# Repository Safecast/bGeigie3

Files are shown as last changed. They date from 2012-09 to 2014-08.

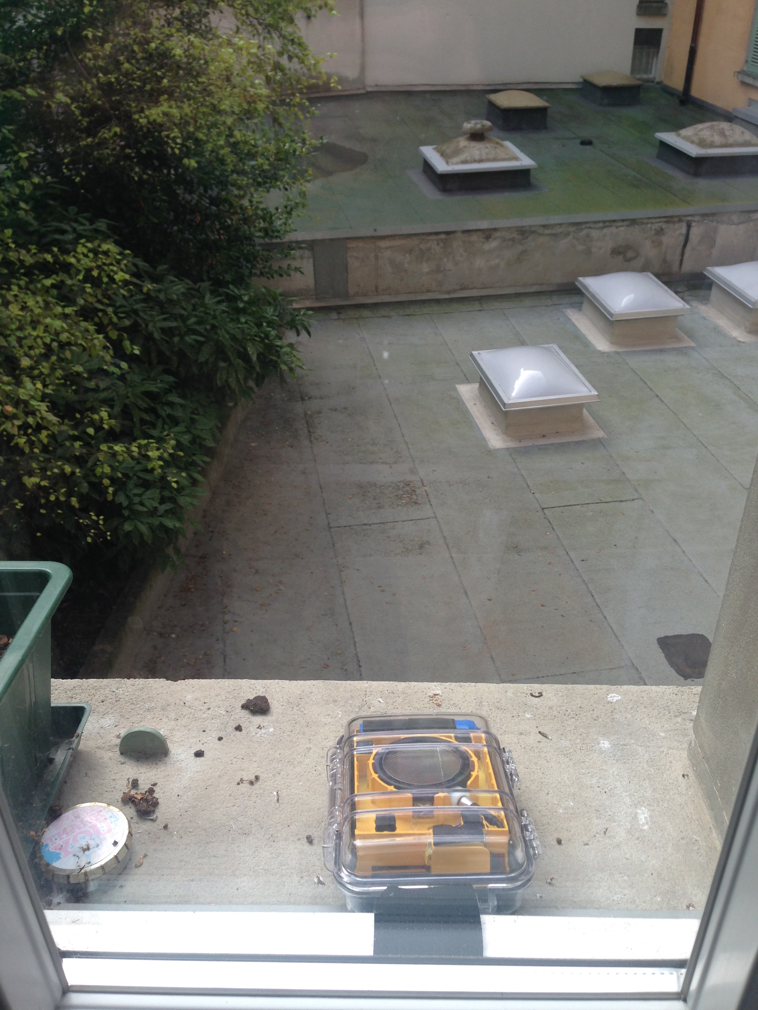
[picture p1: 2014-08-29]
bGeigie3_endurance_august_2014/bGeigie3_placement3.jpg

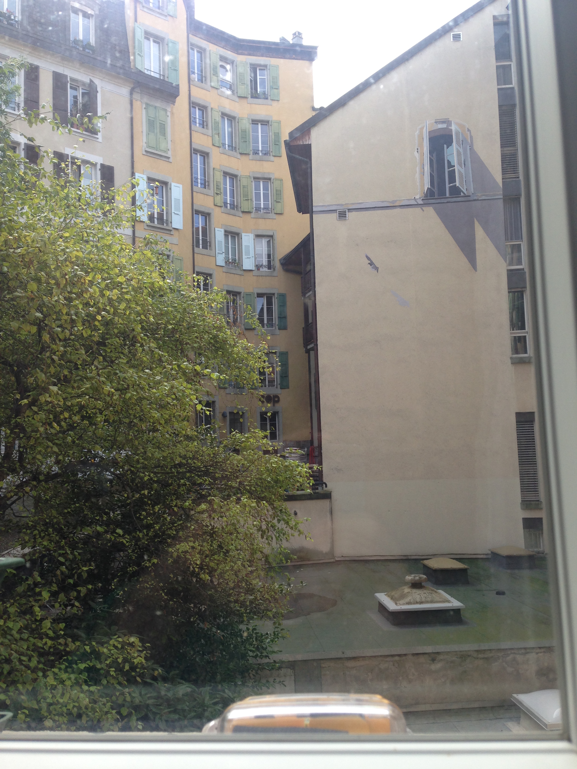
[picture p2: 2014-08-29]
bGeigie3_endurance_august_2014/bGeigie3_placement2.jpg

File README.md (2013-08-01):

## bGeigie3

These are the Eagle CAD files for the bGeigie v3.0 (codename NX) board.

This project is a part of the Safecast radiation monitoring project.
Find out more on [the Safecast website](http://www.safecast.org)

_Note_: although the github repo is named `bGeigie2`, the content is really the **bGeigie3**.

## License

2011-2013 (c) Robin Scheibler
Creative Commons Attribution-ShareAlike 3.0 Unported (CC BY-SA 3.0)
For more details see (http://creativecommons.org/licenses/by-sa/3.0/)

## Produce a bGeigie3

### Gerber

The gerber files can be downloaded [here](https://dl.dropboxusercontent.com/u/78009186/files/bGeigie_v3.4_gerber.zip)

### BOM

The full BOM can be found [here](https://docs.google.com/spreadsheet/ccc?key=0AvXZ3hGhBSusdEQ3NjlfN2hRUnljeTNhNEF5WDNzVWc&usp=sharing).

### Software

* [Firmware](https://github.com/Safecast/SafecastBGeigie)
* [Modded arduino IDE](https://github.com/fakufaku/Arduino) [bin](https://github.com/downloads/fakufaku/Arduino/arduino-Safecast-20121019-macosx.zip)
* [Automated programming tools](https://github.com/Safecast/SCbG3-hexes)

## Tech notes

### Power supply

The system is powered by a LiPo battery providing 4.2V at full charge and dies around 3.5V.

### Battery sensing

The Atmega1284p has two internal analog references: 1.1 or 2.56.

We need to sense the battery voltage between 4.2 and 3.5V.

Let's use a voltage divider with R1 = 100K and R2 = 120K.

Then `Vs = R2/(R1+R2) = 0.54*Vin`, giving a range of 2.3V to 1.89V roughly. We
decide to use the 2.5 reference. This gives use roughly 170 levels of
resolution.

### 50 Ohm trace for the Radio and GPS antennas

* Wiki entry on [microstrips](http://en.wikipedia.org/wiki/Microstrip)
* Microstrip impedance [calculator](http://www.cepd.com/calculators/microstrip.htm)

As a starting point, I used the following values based on [PCB Fusion](http://www.seeedstudio.com/depot/fusion-pcb-service-p-835.html?cPath=185).

* Trace width: 2.815mm (need to look-up tolerance of printing service)
* Substrate height: 1.6mm (standard from PCB Fusion)
* Copper thickness: 0.035mm (guessed from PCB Fusion characteristics, inner layer ?)

give an impedance Z=50.04 Ohms.

### Possible printing services

* [PCB Fusion](http://www.seeedstudio.com/depot/fusion-pcb-service-p-835.html?cPath=185)
* [PCB Cart](http://www.pcbcart.com/) (seems to offer manufacturing too)
* [PCB Express](http://www.pcbexpress.com/)

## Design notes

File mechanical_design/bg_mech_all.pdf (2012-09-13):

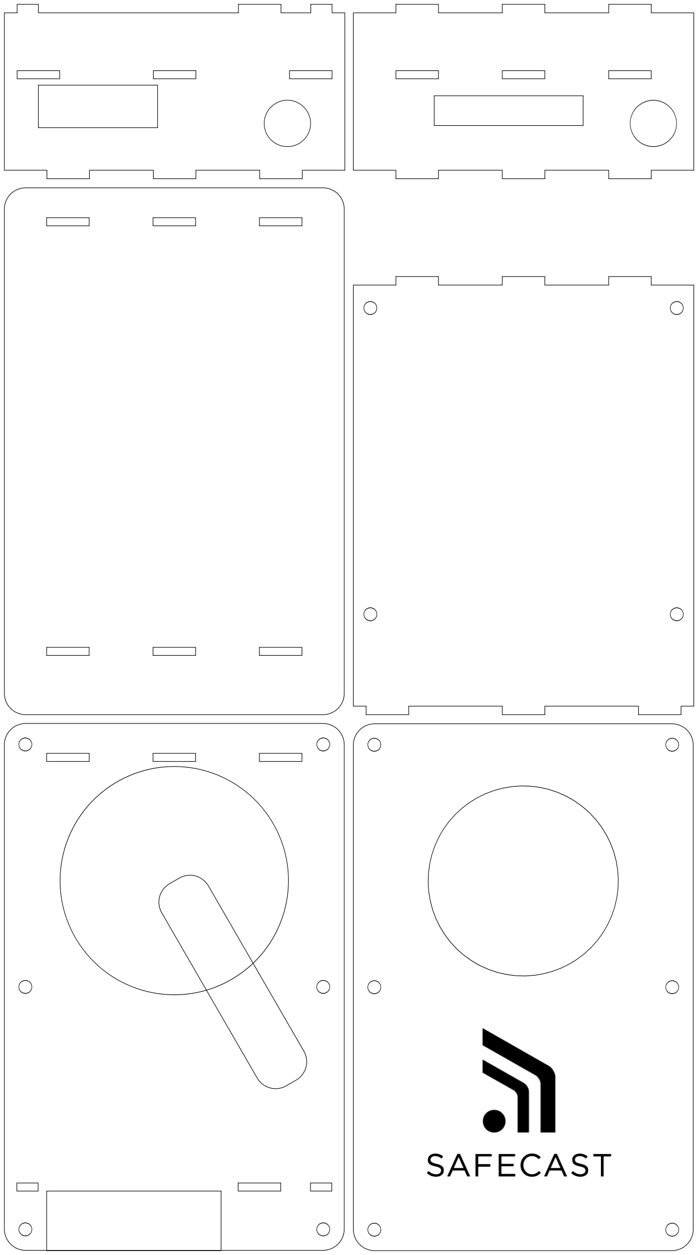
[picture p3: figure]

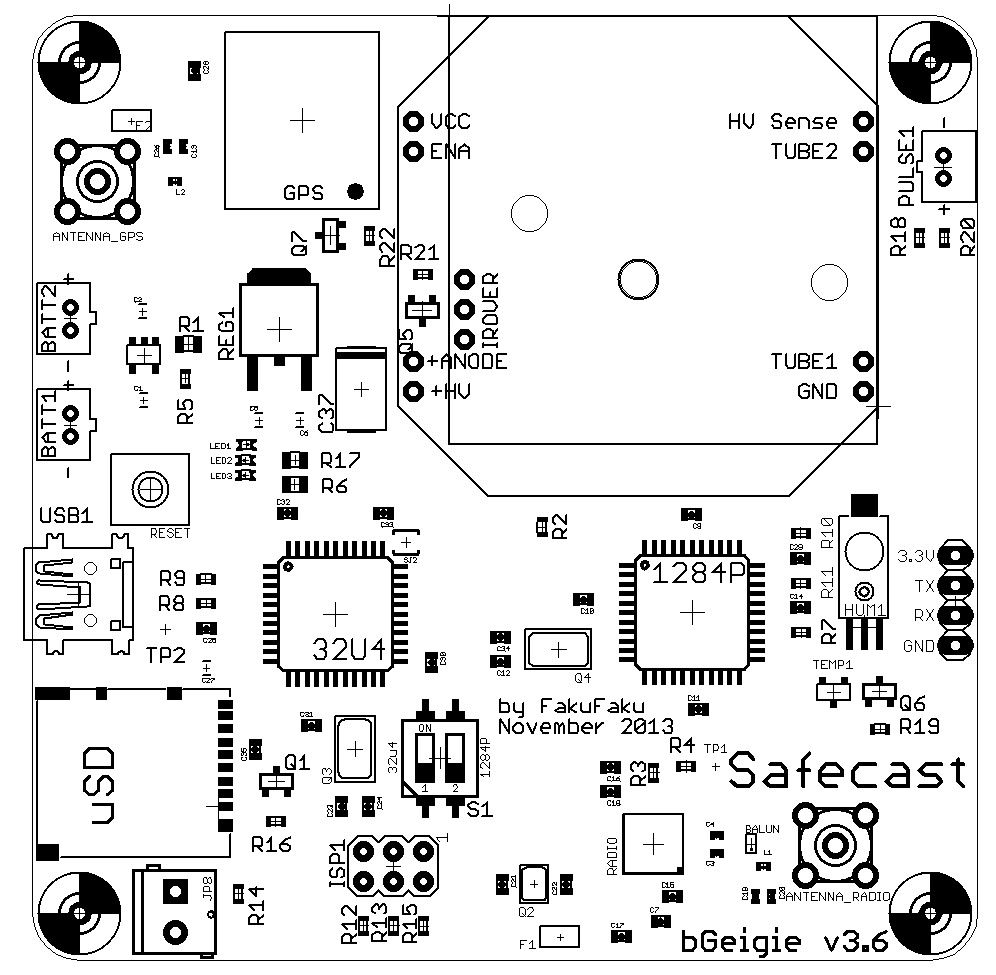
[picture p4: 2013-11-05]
bGeigie3_top.png

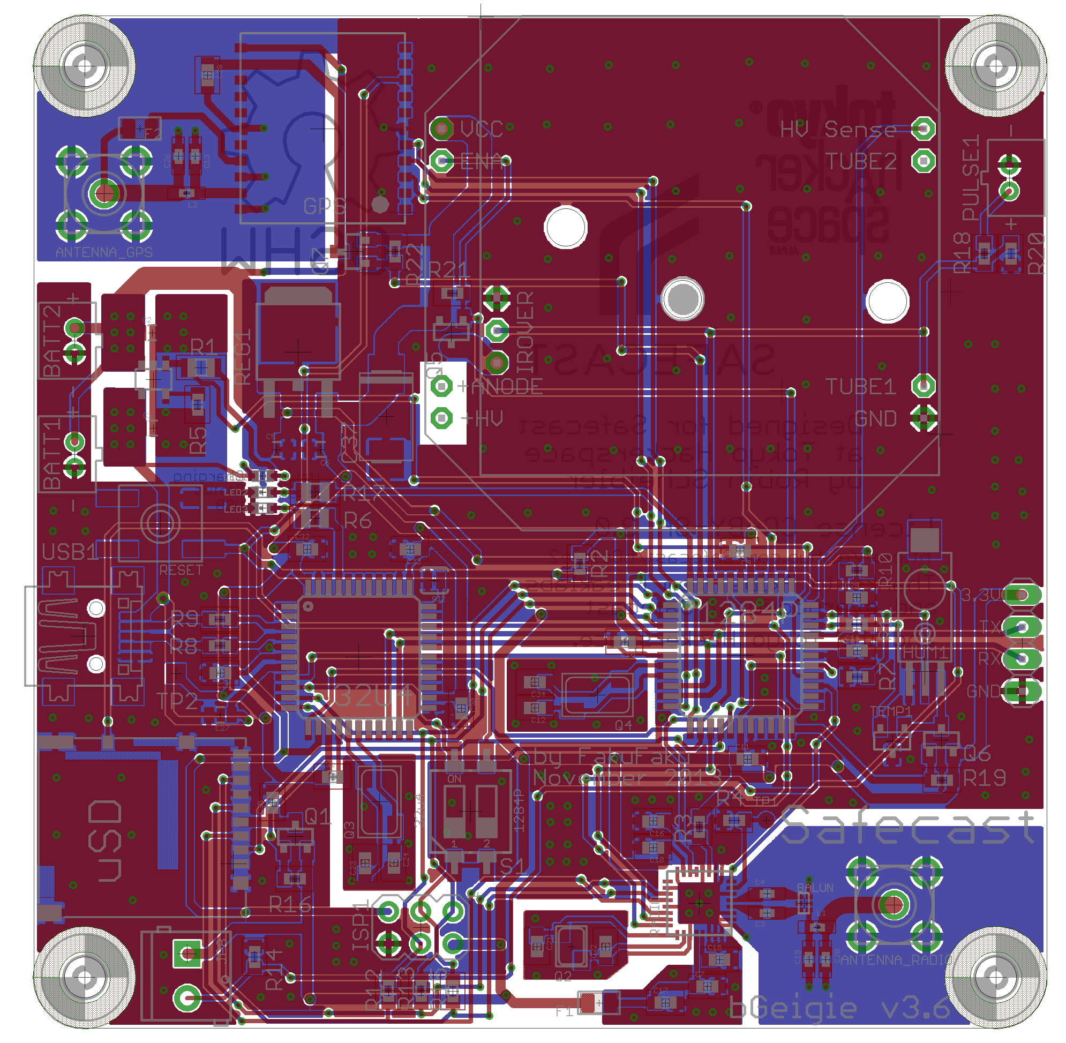
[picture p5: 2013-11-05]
bGeigie3_brd.png

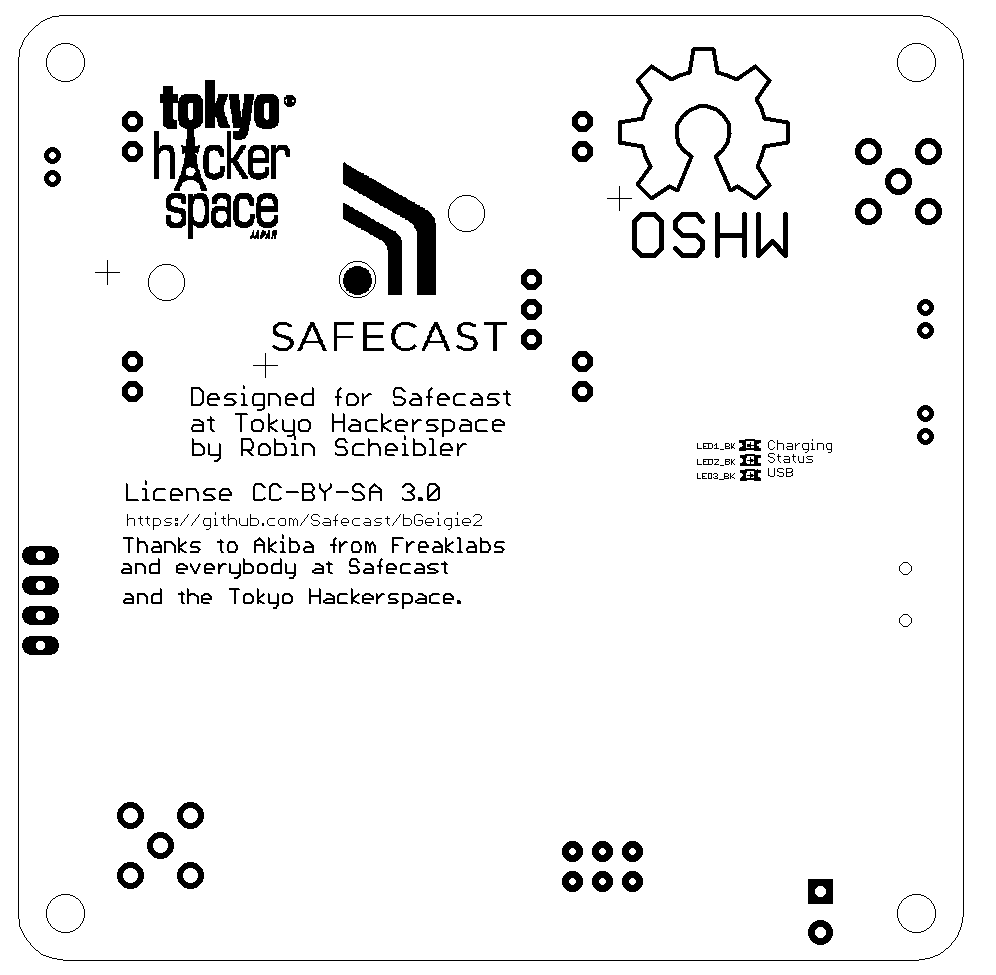
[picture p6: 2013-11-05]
bGeigie3_bot.png

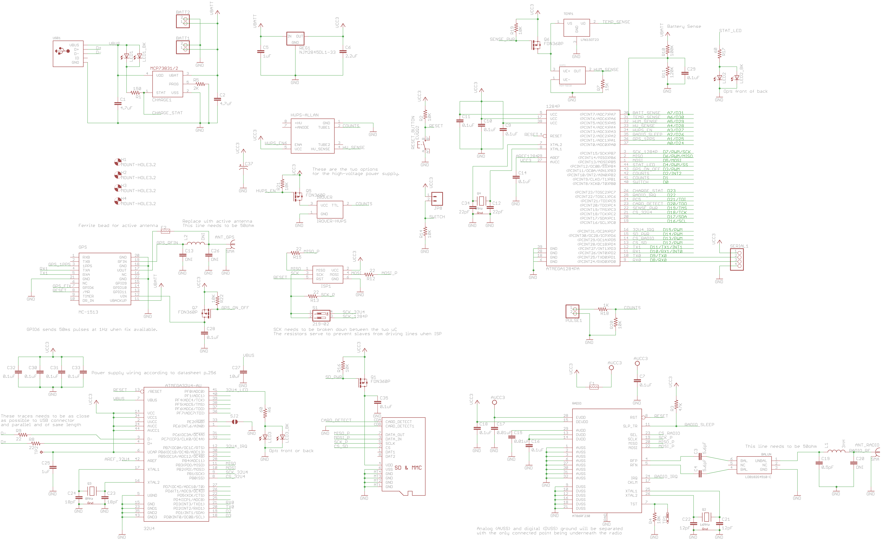
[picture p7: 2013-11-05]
bGeigie3_sch.png

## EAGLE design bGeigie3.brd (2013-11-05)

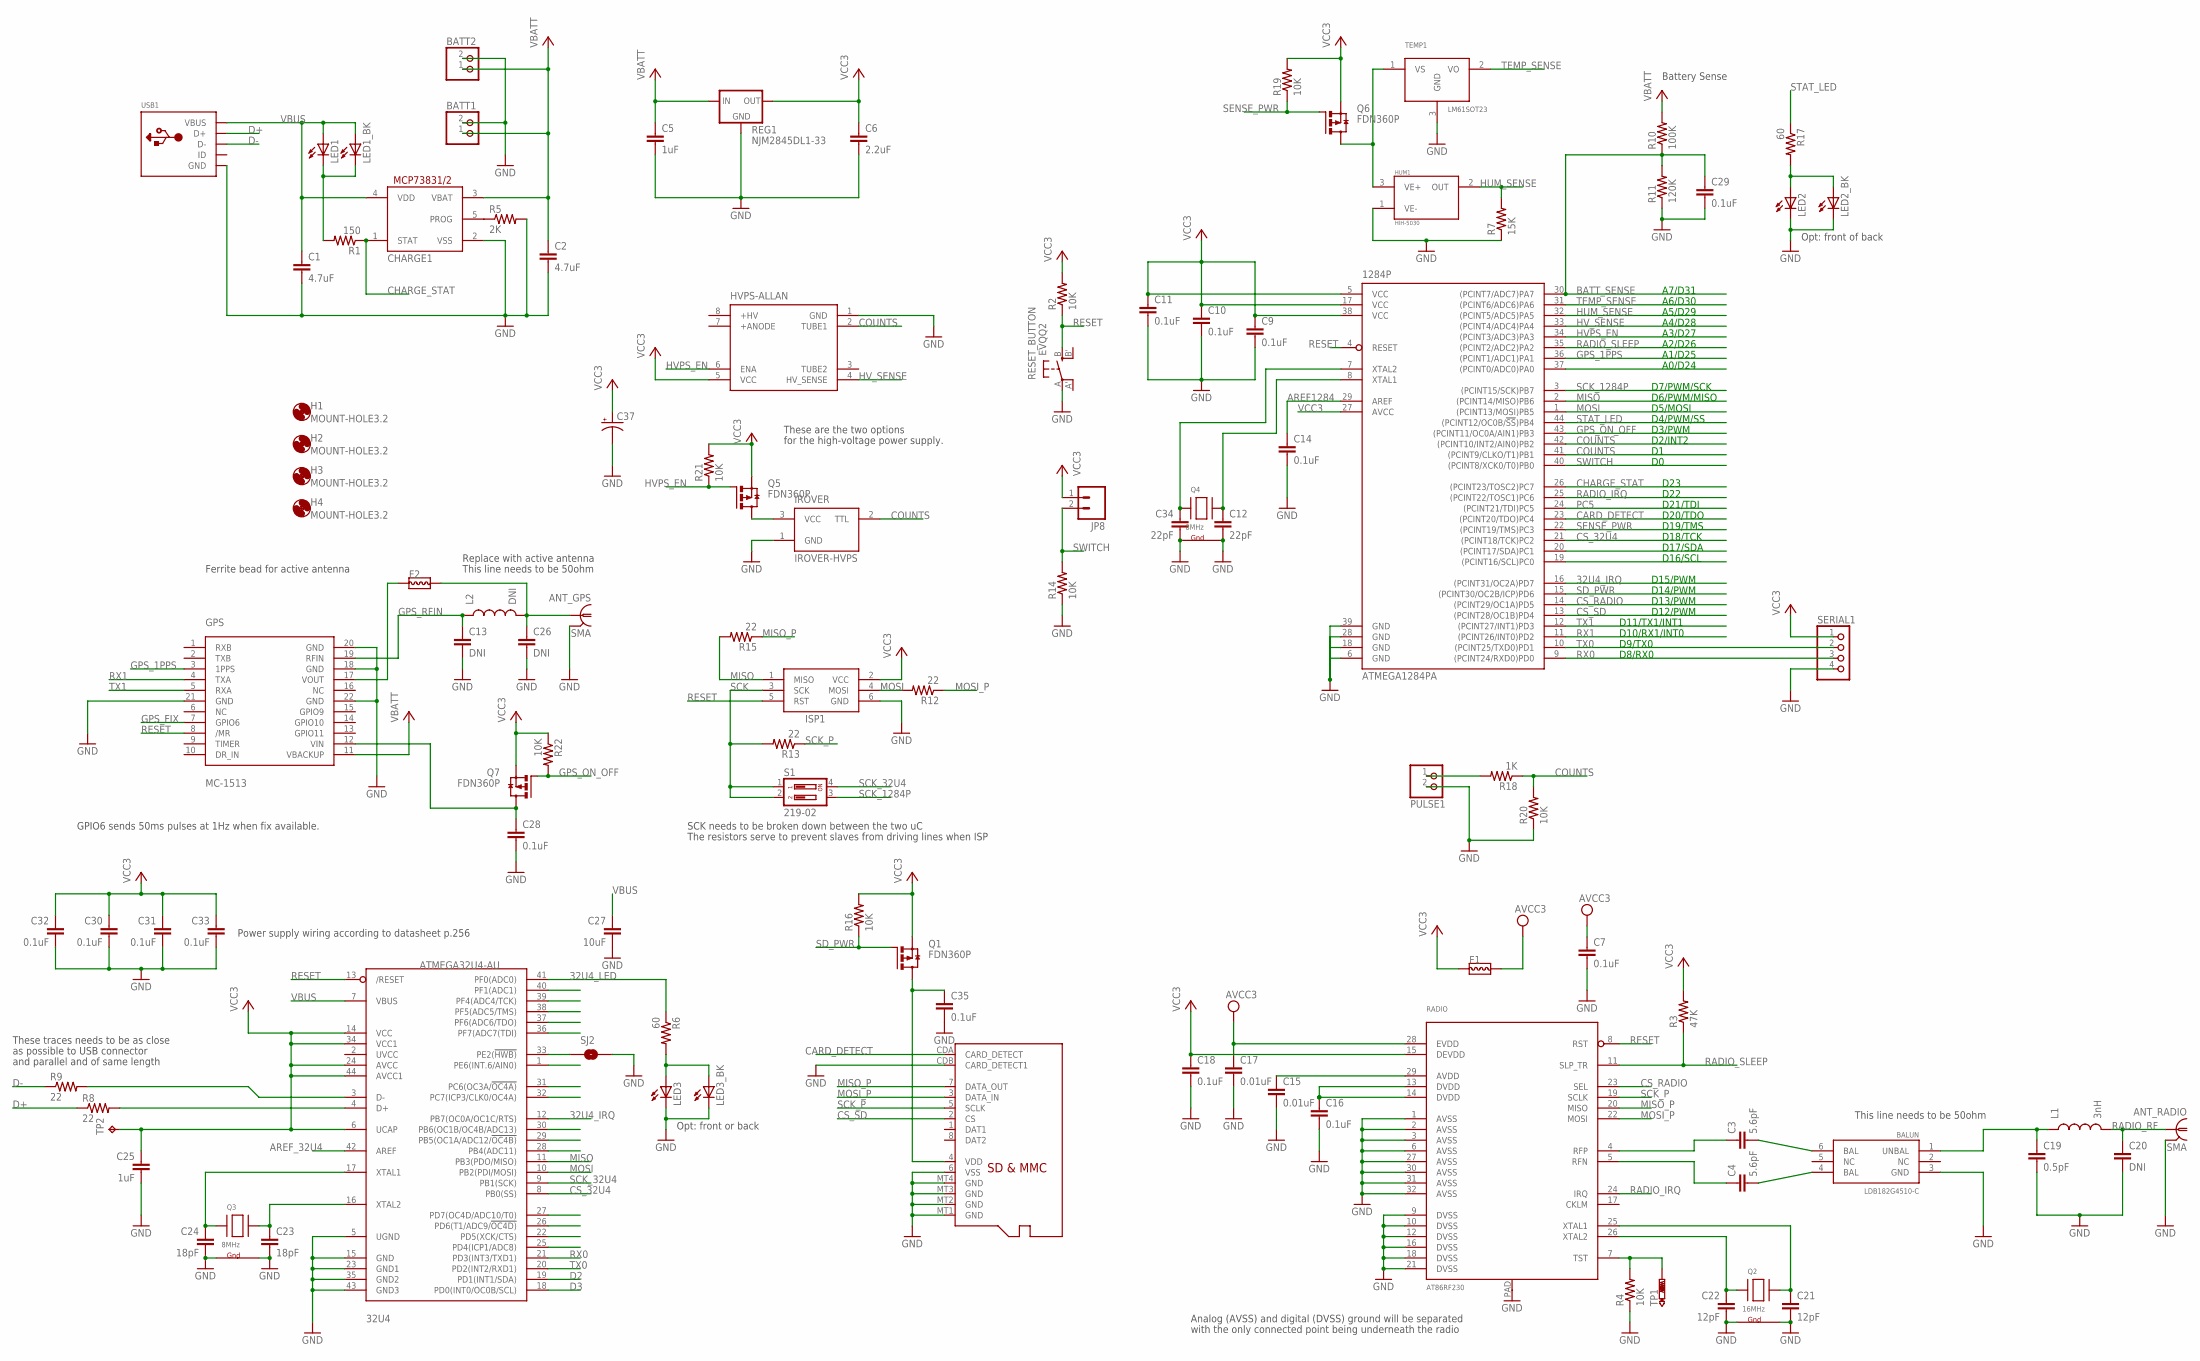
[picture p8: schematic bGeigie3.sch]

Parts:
32U4: ATMEGA32U4-AU; TQFP44
1284P: ATMEGA1284PA; TQFP44
ANT_GPS: SMA; LTI-SASF54GT
ANT_RADIO: SMA; LTI-SASF54GT
BALUN: LDB182G4510-C
BATT1, BATT2: JST_2PIN-THM; JST-PH-2-THM
C1, C2: 4.7uF; 0805
C3, C4: 5.6pF; 0402-CAP
C5: 1uF; 0805
C6: 2.2uF; 0805
C7, C9, C10, C11, C14, C16, C18, C28, C29, C30, C31, C32, C33, C35: 0.1uF; 0603-CAP
C12, C34: 22pF; 0603-CAP
C13, C20, C26: DNI; 0402-CAP
C15, C17: 0.01uF; 0603-CAP
C19: 0.5pF; 0402-CAP
C21, C22: 12pF; 0603-CAP
C23, C24: 18pF; 0603-CAP
C25: 1uF; 0603-CAP
C27: 10uF; 0805
C37: CPOL-USD/7343-31W; D/7343-31W
CHARGE1: MCP73831/OT; SOT23-5L
F1, F2: L-FERRITE-BEAD-0805; 0805
GPS: MC-1513; S4-1513
H1, H2, H3, H4: MOUNT-HOLE3.2; 3,2
HUM1: HIH-5030
HVPS-ALLAN: HVPS-ALLANV2-REVERSE; HVPS-ALLAN-V2-REVERSE
IROVER: IROVER-HVPS; IROVER
ISP1: AVRISP-6; AVRISP
JP8: M023.5MM; SCREWTERMINAL-3.5MM-2
L1: 3nH; C0402
L2: DNI; C0402
LED1, LED1_BK, LED2, LED2_BK, LED3, LED3_BK: LEDCHIPLED_0603; CHIPLED_0603
PULSE1: JST_2PIN-THM; JST-PH-2-THM
Q1, Q5, Q6, Q7: FDN360P; SUPER-SOT3
Q2: 16MHz; NX3225
Q3, Q4: 8MHz; CRYSTAL-5032
R1: 150; R0805
R2, R4, R14, R16, R19, R20, R21, R22: 10K; R0603
R3: 47K; R0603
R5: 2K; R0603
R6, R17: 60; R0805
R7: 15K; R0603
R8, R9, R12, R13, R15: 22; R0603
R10: 100K; R0603
R11: 120K; R0603
R18: 1K; R0603
RADIO: AT86RF230; 32QN1
REG1: NJM2845DL1-33; DPACK
RESET_BUTTON: EVQQ2; EVQ-Q2
S1: 219-02; CTS-219-02
SD: MICROSD; DM3AT-SF-PEJM5
SERIAL1: PINHD-1X4; 1X04
SJ2: SOLDERJUMPERTRACE; SJ_2S-TRACE
TEMP1: LM61SOT23; SOT23
TP1: PTR1B1,27; B1,27
TP2: TPTP15SQ; TP15SQ
USB1: USBMINIB; USB-MINIB

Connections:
32U4_IRQ: 32U4.12 (PB7(OC0A/OC1C/RTS)), 1284P.16 ((PCINT31/OC2A)PD7)
32U4_LED: 32U4.41 (PF0(ADC0)), R6.1
32U4_PC7: 32U4.32 (PC7(ICP3/CLK0/OC4A))
AREF1284: 1284P.29 (AREF), C14.1
AREF_32U4: 32U4.42 (AREF)
AVCC3: C7.1, C17.1, F1.2, RADIO.28 (EVDD)
BATT_SENSE: 1284P.30 ((PCINT7/ADC7)PA7), C29.1, R10.1, R11.2
CARD_DETECT: 1284P.23 ((PCINT20/TDO)PC4), SD.CDA (CARD_DETECT)
CHARGE_STAT: 1284P.26 ((PCINT23/TOSC2)PC7), CHARGE1.1 (STAT), R1.1
COUNTS: 1284P.41 ((PCINT9/CLKO/T1)PB1), 1284P.42 ((PCINT10/INT2/AIN0)PB2), HVPS-ALLAN.2 (TUBE1), IROVER.2 (TTL), R18.1, R20.2
CS_32U4: 32U4.8 (PB0(SS)), 1284P.21 ((PCINT18/TCK)PC2)
CS_RADIO: 1284P.14 ((PCINT29/OC1A)PD5), RADIO.23 (SEL)
CS_SD: 1284P.13 ((PCINT28/OC1B)PD4), SD.2 (CS)
D2: 32U4.19 (PD1(INT1/SDA))
D3: 32U4.18 (PD0(INT0/OC0B/SCL))
D+: R8.1, USB1.D+
D-: R9.1, USB1.D-
GND: 32U4.5 (UGND), 32U4.15 (GND), 32U4.23 (GND1), 32U4.35 (GND2), 32U4.43 (GND3), 1284P.6 (GND), 1284P.18 (GND), 1284P.28 (GND), 1284P.39 (GND), ANT_GPS.2 (GND), ANT_GPS.3 (GND), ANT_GPS.4 (GND), ANT_GPS.5 (GND), ANT_RADIO.2 (GND), ANT_RADIO.3 (GND), ANT_RADIO.4 (GND), ANT_RADIO.5 (GND), BALUN.3 (GND), BATT1.2 (1), BATT2.2 (1), C1.2, C2.2, C5.2, C6.2, C7.2, C9.2, C10.2, C11.2, C12.2, C13.2, C14.2, C15.2, C16.2, C17.2, C18.2, C19.2, C20.2, C21.2, C22.2, C23.2, C24.2, C25.2, C26.2, C27.2, C28.2, C29.2, C30.2, C31.2, C32.2, C33.2, C34.2, C35.2, C37.-, CHARGE1.2 (VSS), GPS.18 (GND), GPS.20 (GND), GPS.21 (GND), GPS.22 (GND), HUM1.1 (VE-), HVPS-ALLAN.1 (GND), IROVER.1 (GND), ISP1.6 (GND), LED2.C, LED2_BK.C, LED3.C, LED3_BK.C, PULSE1.2 (1), Q2.2 (G2), Q2.4 (G1), Q3.2 (G1), Q3.4 (G2), Q4.2 (G1), Q4.4 (G2), R4.1, R5.2, R7.1, R11.1, R14.1, R20.1, RADIO.1 (AVSS), RADIO.2 (AVSS), RADIO.3 (AVSS), RADIO.6 (AVSS), RADIO.9 (DVSS), RADIO.10 (DVSS), RADIO.12 (DVSS), RADIO.16 (DVSS), RADIO.18 (DVSS), RADIO.21 (DVSS), RADIO.27 (AVSS), RADIO.30 (AVSS), RADIO.31 (AVSS), RADIO.32 (AVSS), RADIO.PAD, REG1.4 (GND), RESET_BUTTON.A, SD.6 (VSS), SD.CDB (CARD_DETECT1), SD.MT1 (GND), SD.MT2 (GND), SD.MT3 (GND), SD.MT4 (GND), SERIAL1.4, SJ2.2, TEMP1.3 (GND), USB1.GND
GPS_1PPS: 1284P.36 ((PCINT1/ADC1)PA1), GPS.3 (1PPS)
GPS_FIX: GPS.7 (GPIO6)
GPS_ON_OFF: 1284P.43 ((PCINT11/OC0A/AIN1)PB3), Q7.1 (G), R22.2
GPS_RFIN: C13.1, GPS.19 (RFIN), L2.1
HUM_SENSE: 1284P.32 ((PCINT5/ADC5)PA5), HUM1.2 (OUT), R7.2
HVPS_EN: 1284P.34 ((PCINT3/ADC3)PA3), HVPS-ALLAN.6 (ENA), Q5.1 (G), R21.1
HV_SENSE: 1284P.33 ((PCINT4/ADC4)PA4), HVPS-ALLAN.4 (HV_SENSE)
MISO: 32U4.11 (PB3(PDO/MISO)), 1284P.2 ((PCINT14/MISO)PB6), ISP1.1 (MISO), R15.2
MISO_P: R15.1, RADIO.20 (MISO), SD.7 (DATA_OUT)
MOSI: 32U4.10 (PB2(PDI/MOSI)), 1284P.1 ((PCINT13/MOSI)PB5), ISP1.4 (MOSI), R12.2
MOSI_P: R12.1, RADIO.22 (MOSI), SD.3 (DATA_IN)
unnamed: 32U4.16 (XTAL2), C23.1, Q3.3 (X2)
unnamed: LED1.C, LED1_BK.C, R1.2
unnamed: PULSE1.1 (2), R18.2
unnamed: CHARGE1.5 (PROG), R5.1
unnamed: BALUN.4 (BAL), C4.2
unnamed: 1284P.8 (XTAL1), C12.1, Q4.3 (X2)
unnamed: 1284P.7 (XTAL2), C34.1, Q4.1 (X1)
unnamed: C16.1, RADIO.13 (DVDD), RADIO.14 (DVDD)
unnamed: C15.1, RADIO.29 (AVDD)
unnamed: ANT_GPS.1, C26.1, F2.2, L2.2
unnamed: C21.1, Q2.3 (X2), RADIO.25 (XTAL1)
unnamed: C22.1, Q2.1 (X1), RADIO.26 (XTAL2)
unnamed: F2.1, GPS.17 (VOUT)
unnamed: IROVER.3 (VCC), Q5.3 (D)
unnamed: LED3.A, LED3_BK.A, R6.2
unnamed: R4.2, RADIO.7 (TST), TP1.TP
unnamed: BALUN.6 (BAL), C3.2
unnamed: C4.1, RADIO.5 (RFN)
unnamed: C3.1, RADIO.4 (RFP)
unnamed: BALUN.1 (UNBAL), C19.1, L1.1
unnamed: C28.1, GPS.12 (VIN), Q7.3 (D)
unnamed: 32U4.17 (XTAL1), C24.1, Q3.1 (X1)
unnamed: LED2.A, LED2_BK.A, R17.2
unnamed: 32U4.3 (D-), R9.2
unnamed: 32U4.4 (D+), R8.2
unnamed: 32U4.33 (PE2(!HWB)), SJ2.1
PA0: 1284P.37 ((PCINT0/ADC0)PA0)
PC0: 1284P.19 ((PCINT16/SCL)PC0)
PC1: 1284P.20 ((PCINT17/SDA)PC1)
PC5: 1284P.24 ((PCINT21/TDI)PC5)
RADIO_IRQ: 1284P.25 ((PCINT22/TOSC1)PC6), RADIO.24 (IRQ)
RADIO_RF: ANT_RADIO.1, C20.1, L1.2
RADIO_SLEEP: 1284P.35 ((PCINT2/ADC2)PA2), R3.1, RADIO.11 (SLP_TR)
RESET: 32U4.13 (/RESET), 1284P.4 (RESET), GPS.8 (/MR), ISP1.5 (RST), R2.1, RADIO.8 (RST), RESET_BUTTON.B (S)
RX0: 32U4.21 (PD3(INT3/TXD1)), 1284P.9 ((PCINT24/RXD0)PD0), SERIAL1.3
RX1: 1284P.11 ((PCINT26/INT0)PD2), GPS.4 (TXA)
SCK: ISP1.3 (SCK), R13.2, S1.1, S1.2
SCK_32U4: 32U4.9 (PB1(SCK)), S1.4
SCK_1284P: 1284P.3 ((PCINT15/SCK)PB7), S1.3
SCK_P: R13.1, RADIO.19 (SCLK), SD.5 (SCLK)
SD_PWR: 1284P.15 ((PCINT30/OC2B/ICP)PD6), Q1.1 (G), R16.1
SENSE: HUM1.3 (VE+), Q6.3 (D), TEMP1.1 (VS)
SENSE_PWR: 1284P.22 ((PCINT19/TMS)PC3), Q6.1 (G), R19.1
STAT_LED: 1284P.44 ((PCINT12/OC0B/!SS!)PB4), R17.1
SWITCH: 1284P.40 ((PCINT8/XCK0/T0)PB0), JP8.2, R14.2
TEMP_SENSE: 1284P.31 ((PCINT6/ADC6)PA6), TEMP1.2 (VO)
TX0: 32U4.20 (PD2(INT2/RXD1)), 1284P.10 ((PCINT25/TXD0)PD1), SERIAL1.2
TX1: 1284P.12 ((PCINT27/INT1)PD3), GPS.5 (RXA)
VBATT: BATT1.1 (2), BATT2.1 (2), C2.1, C5.1, CHARGE1.3 (VBAT), GPS.11 (VBACKUP), R10.2, REG1.1 (IN)
VBUS: 32U4.7 (VBUS), C1.1, C27.1, CHARGE1.4 (VDD), LED1.A, LED1_BK.A, USB1.VBUS
VCC3: 32U4.6 (UCAP), 32U4.14 (VCC), 32U4.24 (AVCC), 32U4.34 (VCC1), 32U4.44 (AVCC1), 1284P.5 (VCC), 1284P.17 (VCC), 1284P.27 (AVCC), 1284P.38 (VCC), C6.1, C9.1, C10.1, C11.1, C18.1, C25.1, C30.1, C31.1, C32.1, C33.1, C37.+, F1.1, HVPS-ALLAN.5 (VCC), ISP1.2 (VCC), JP8.1, Q1.2 (S), Q5.2 (S), Q6.2 (S), Q7.2 (S), R2.2, R3.2, R16.2, R19.2, R21.2, R22.1, RADIO.15 (DEVDD), REG1.3 (OUT), SERIAL1.1, TP2.TP
VDD: C35.1, Q1.3 (D), SD.4 (VDD)

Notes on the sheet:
D2/INT2
D3/PWM
D4/PWM/SS
D5/MOSI
D6/PWM/MISO
D7/PWM/SCK
D8/RX0
D9/TX0
D11/TX1/INT1
D10/RX1/INT0
D12/PWM
D13/PWM
D14/PWM
D15/PWM
D16/SCL
D17/SDA
D18/TCK
D19/TMS
D20/TDO
D21/TDI
D22
D23
A0/D24
A1/D25
A2/D26
A3/D27
A4/D28
A5/D29
A6/D30
A7/D31
Battery Sense
GPIO6 sends 50ms pulses at 1Hz when fix available.
SCK needs to be broken down between the two uC
The resistors serve to prevent slaves from driving lines when ISP
This line needs to be 50ohm
These traces needs to be as close
as possible to USB connector
and parallel and of same length
Replace with active antenna
Analog (AVSS) and digital (DVSS) ground will be separated

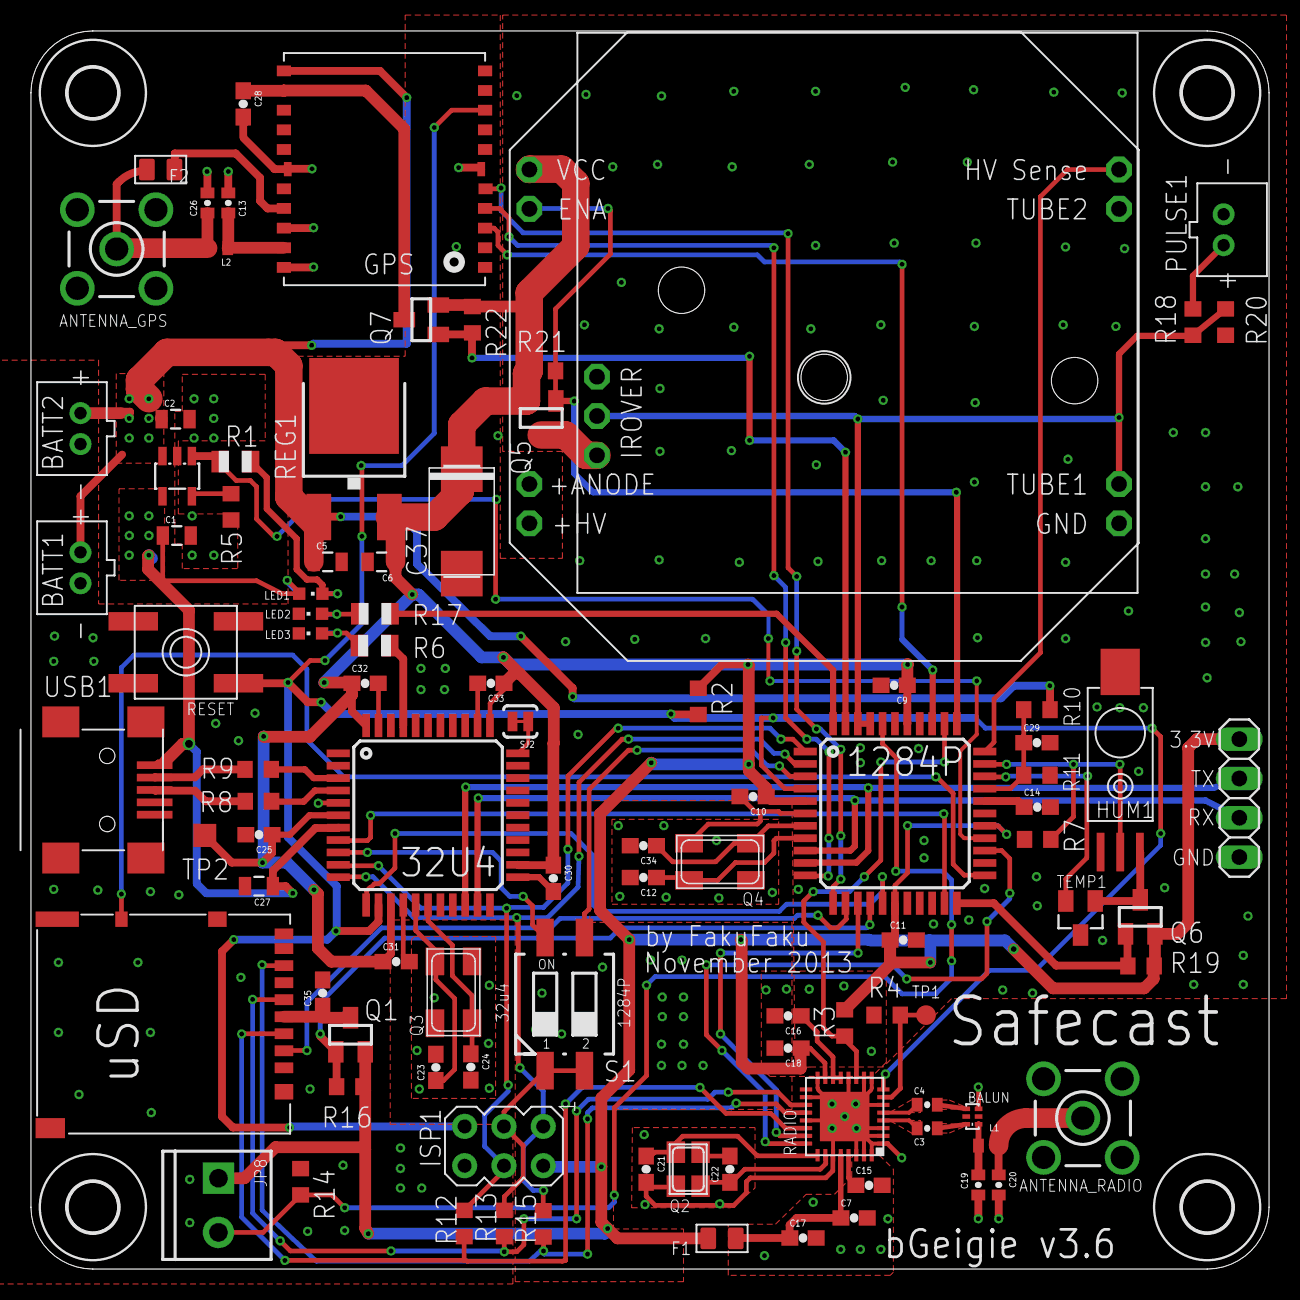
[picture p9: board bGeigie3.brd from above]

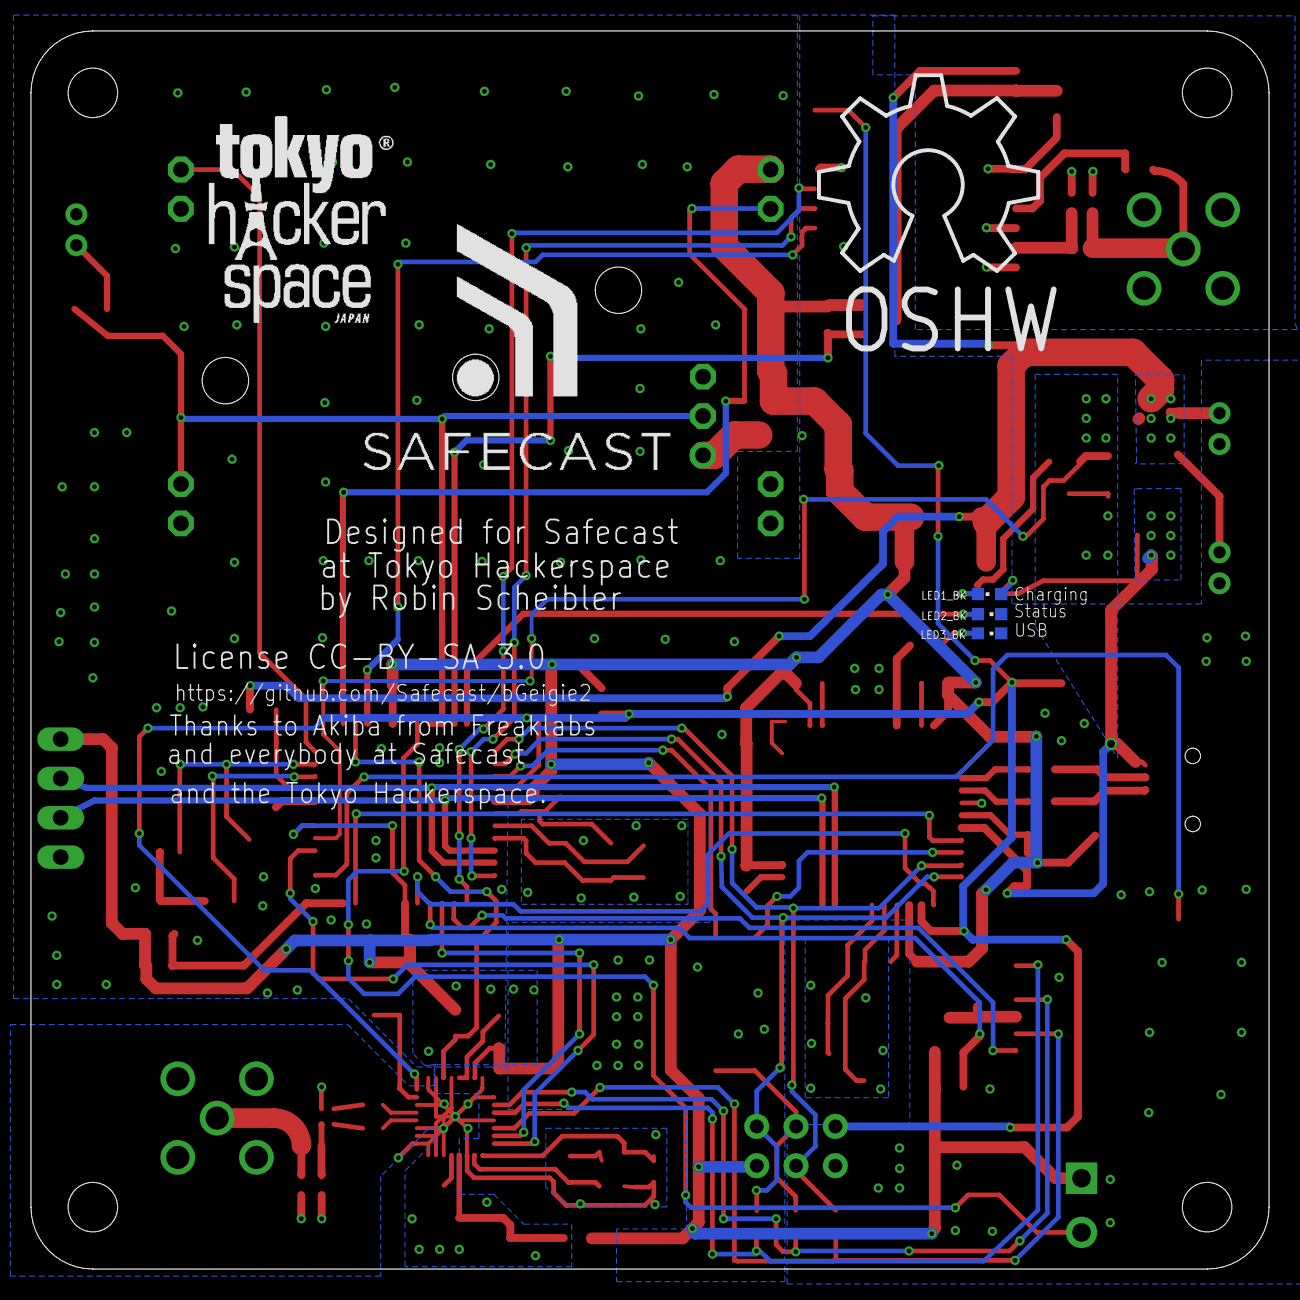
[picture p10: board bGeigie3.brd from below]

Board: 2 copper layers, 80.0 x 80.0 mm, 107 parts (6 on the bottom side), 72 nets.

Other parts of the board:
U$1: SAFECAST_LOGO
U$3: THS
U$4: OSHW_10X500_NOTEXT

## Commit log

2011-12-08 Added content and License to README file. Added .gitignore file and placeholder file for Bill Of Material (BOM.txt).
2011-12-08 Added junk files from Eagle CAD to .gitignore
2011-12-08 Added TODO.txt file to keep track of what's left to do.
    [bGeigie2.sch]
2011-12-08 Added png schematics file
    [bGeigie2.sch]
2011-12-19 Commiting current status of 'low-power' version.
    [bGeigie2.sch]
2011-12-27 Added chipselects, IRQ. 1284p is now master of all devices. Optional serial connection between 32u4 and 1284p.
    [bGeigie2.sch]
2012-01-06 Added boost converter. Edited TODO with current tasks. Now board is at 3.3V.
    [bGeigie2.sch]
2012-01-07 Started to check all foot print, began the BOM.
    [bGeigie2.sch]
2012-01-09 UPdated todo, started checking all footprints.
    [bGeigie2.sch]
2012-01-12 More details. Updated TODO.
    [bGeigie2.sch]
2012-01-13 Updated README with impedance of RF line (GPS, Radio), and printing services.
2012-01-13 More changes
    [bGeigie2.sch]
2012-01-13 Added board file.|
    [bGeigie2.brd]
2012-01-17 Schematics nearly done. (Will need HVPS soon though). Added and started the board layout.
    [bGeigie2.brd, bGeigie2.sch]
2012-01-17 Updated schematics png, .gitignore.
2012-01-19 Advanced board layout a bit. Corrected few bugs in schematics.
    [bGeigie2.brd, bGeigie2.sch]
2012-02-19 Moved GPS, laid radio, more wires laid out.
    [bGeigie2.brd, bGeigie2.sch]
2012-02-20 Pulled some more wires. Finished GPS.
    [bGeigie2.brd]
2012-02-20 Updated BOM, layout and schematics png.
2012-02-25 Mostly finished routing.
    [bGeigie2.brd]
2012-02-25 Modified High Voltage board for v2.0. Updated PNGs.
    [bGeigie2.brd, bGeigie2.sch]
2012-02-27 Corrected crystal. Cleaned labels. Added pull-down on audio jack. Added humidity sensor. Transistor on sensors supplies.
    [bGeigie2.brd, bGeigie2.sch]
2012-02-29 Added iRover trace. Connected 32u4 to interrupt of 1284p. Updated BOM.
    [bGeigie2.brd, bGeigie2.sch]
2012-03-01 Corrected hole sizes of iRover and Allan's HVPS board.
    [bGeigie2.brd, bGeigie2.sch]
2012-03-05 Corrected audio jack footprint.
    [bGeigie2.brd, bGeigie2.sch]
2012-03-05 Added Safecast and THS logo.
    [bGeigie2.brd]
2012-03-06 Removed bottom LED labels.
    [bGeigie2.brd]
2012-03-06 Added SMD footprint for LEDs on backside.
    [bGeigie2.brd, bGeigie2.sch]
2012-03-07 Corrected values of R10, R11 and C5.
    [bGeigie2.brd, bGeigie2.sch]
2012-03-07 Changed info about battery sensing in README.
2012-03-08 Changed footprint of 8MHz crystals.
    [bGeigie2.brd, bGeigie2.sch]
2012-03-31 Rerouted MOSI to 32u4
    [bGeigie2.brd]
2012-04-11 Replaced bipolar pnp transistors by p-channel mosfet.
    [bGeigie2.sch]
2012-04-11 Added mosfet on GPS powerline. Modified GPS library part to conform to datasheet v1.4.
    [bGeigie2.sch]
2012-04-12 Placed and routed MOSFET transistors.
    [bGeigie2.brd]
2012-04-12 Added LED for 32u4 on pin 13.
    [bGeigie2.sch]
2012-04-12 Moved 1284p led to arduino digital pin 13, routed 32u4 led on board.
    [bGeigie2.brd, bGeigie2.sch]
2012-04-12 Corrected SPI bug.
    [bGeigie2.brd, bGeigie2.sch]
2012-04-12 Make board corners rounded.
    [bGeigie2.brd]
2012-04-24 Added credits, logo and art. Moved bead from gps antenna power.
    [bGeigie2.brd, bGeigie2.sch]
2012-06-08 Reduced board size. Implemented everything learnt from prototypes. Go to version 3.3.
    [bGeigie2.brd, bGeigie2.sch]
2012-06-08 Small connection was missing on a radio pad.
    [bGeigie2.brd]
2012-06-09 Put C13, C26, and C19, C20 to different grounds. Updated layout PNG.
    [bGeigie2.brd]
2012-06-09 Finalizing before fab.
    [bGeigie2.brd, bGeigie2.sch]
2012-06-22 Corrected bug (unconnected wires). Rewired VCC so that power to 32u4 and 1284 are fairly independant, easy to split.
    [bGeigie2.brd]
2012-07-07 Added big tantalum cap on power supply line to HVPS.
    [bGeigie2.brd, bGeigie2.sch]
2012-07-27 Added dot in silkscreen of GPS footprint for orientation of chip.
    [bGeigie2.brd, bGeigie2.sch]
2012-07-27 Renamed board png to bGeigie2_brd.png for consistency.
2012-09-13 Moved some labels. Added some silkscreen for 8MHz crystals. Added some tDocu for art on humidity sensor.
    [bGeigie2.brd, bGeigie2.sch]
2012-10-28 Updated silkscreen with missing labels.
    [bGeigie2.brd]
2013-08-01 Cleaning up. Upgrading name. Adding to README.
    [bGeigie3.brd, bGeigie3.sch]
2013-11-02 Moved to Eagle CAD 6.5.0 and removed serial headers. Connect both serials together.
    [bGeigie3.brd, bGeigie3.sch]
2013-11-05 Added serial header for debugging.
    [bGeigie3.brd, bGeigie3.sch]

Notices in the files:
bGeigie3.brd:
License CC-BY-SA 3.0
